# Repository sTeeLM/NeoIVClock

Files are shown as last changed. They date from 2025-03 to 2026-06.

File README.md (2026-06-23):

# NeoIVClock

[简体中文](#简体中文) | [English](#english)

---

## 简体中文

基于 ESP32-S3 主控的环境监测桌面时钟，使用前苏联 IV-18 荧光数码管与 0.96寸 OLED 作为显示输出。

### 功能特性

* **时间管理**：支持 Wi-Fi 连接 NTP 自动对时；支持最多 10 组独立闹钟设置（可配重复周期及声音）；具备秒表与倒计时功能。
* **语音报时**：集成 DFPlayer Mini 模块，支持整点语音报时（可设置免打扰时段）。
* **多维传感器监测**：
  * 温度、湿度 (AHT21)
  * 大气压强 (BMP280)
  * TVOC、eCO2 (ENS160)
  * PM2.5、甲醛等颗粒物及有害气体 (PM5300ST)
* **数据双模上报**：
  * **Wi-Fi**：定时通过自定义 HTTPS 接口发送数据至自建服务器。
  * **蓝牙**：采用 BTHome v2 协议进行 BLE 广播，支持 Home Assistant 免配对直接识别。

### 硬件架构

* **主控**：ESP32-S3 (ESP-IDF 架构)
* **显示**：IV-18 荧光管（主时间） + 0.96寸 OLED（环境数据与配置菜单）
* **供电与驱动**：5V Type-C 输入。通过 XL6007 升压电路产生 30V~50V 高压供给 IV-18，并使用 MAX6921 移位寄存器驱动荧光管。
* **外设连接**：
  * AHT21 / BMP280 / ENS160 / DS3231 挂载于同一路 I2C 总线
  * PM5300ST 与 DFPlayer Mini 分别独占一路 UART 串口

### 关键设计要点

* **温湿度防热干扰布局**：由于板载了 XL6007 高压升压电路，工作时伴随一定的发热量。AHT21 传感器在 PCB 布局时已远离升压区域与 ESP32-S3 主控芯片，并通过 PCB 开槽隔离与外壳独立风道设计，避免了板载热量传导导致的温度偏高、湿度偏低问题。
* **电源去耦与电磁兼容**：PMS5300ST 激光粉尘传感器在风扇启动和采样瞬间存在较大的脉冲电流。供电设计中在 5V 输入端配置了充足的滤波电容，有效解决了因瞬态电压跌落引起的 VFD 屏幕闪烁问题，并做好了走线隔离以避免干扰 DFPlayer 模块的音频输出。
* **VFD 刷新与消隐保护**：使用 MAX6921 驱动 IV-18 荧光管时，在驱动代码中严格控制了刷新占空比并加入动态消隐机制，消除了数码管鬼影。同时引入了软件夜间自动调暗与滚屏保护逻辑，延长荧光管使用寿命并减缓局部老化。
* **双核异步调度与状态机设计**：为了降低多任务并发的复杂度，系统软件引入了状态机设计。同时充分利用了 ESP32-S3 的双核硬件资源：一个核心（Core 0）专门负责系统的 UI 刷新、界面交互与外设控制；另一个核心（Core 1）负责管理传感器数据轮询、UART/I2C 通信以及 Wi-Fi/BLE 物联网协议栈，确保整机在高负载下不卡顿、不丢包。
* **硬件 RTC 时间双重保障**：引入了高精度硬件时钟芯片 DS3231 随 I2C 总线运行。在无网络环境或 Wi-Fi 连接失败时，设备依然能够通过板载电池和高精度温补晶振在断网期间保持高精度的本地走时，与 NTP 网络对时形成双重互补。
* **激光传感器间歇休眠与延寿**：考虑到 PMS5300ST 激光粉尘传感器内的激光二极管与采样风扇存在机械和物理寿命限制，软件设计了间歇采样与低功耗休眠逻辑。传感器无需 24 小时连续运转，而是定时唤醒并预热风扇，完成数据采集后立即将其送入休眠模式，极大延长了传感器的使用寿命并减少了积灰。

### 项目实物

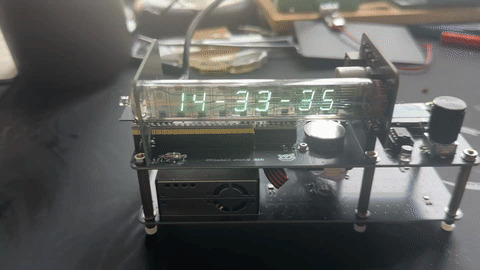
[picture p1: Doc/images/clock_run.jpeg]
图片


视频

### 开源协议

本项目采用 [MIT](LICENSE) 协议开源。

---

## English

An ESP32-S3-based smart desktop clock and environmental monitor, utilizing a USSR IV-18 (ИВ-18) VFD tube and a 0.96" OLED display.

### Features

* **Time Management**: Automatically synchronizes time via Wi-Fi NTP. Supports up to 10 independent alarms with configurable repetition cycles and ringtones. Built-in stopwatch and countdown timer.
* **Voice Chime**: Integrated with a DFPlayer Mini module to support hourly voice announcements with a customizable Do-Not-Disturb period.
* **Multi-Dimensional Environmental Monitoring**:
  * Temperature & Humidity (AHT21)
  * Barometric Pressure (BMP280)
  * TVOC & eCO2 (ENS160)
  * PM2.5, Formaldehyde, and other particulates/hazardous gases (PM5300ST)
* **Dual-Mode Data Reporting**:
  * **Wi-Fi**: Periodically posts environmental data via a custom HTTPS JSON payload to a self-hosted server.
  * **Bluetooth**: Broadcasts via the BTHome v2 protocol, enabling zero-configuration auto-discovery in Home Assistant.

### Hardware Architecture

* **MCU**: ESP32-S3 (Developed natively using ESP-IDF)
* **Display**: IV-18 VFD tube (primary time display) + 0.96" OLED (environmental stats and configuration menu)
* **Power & Drive**: 5V Type-C input. An onboard XL6007 boost converter steps up voltage to 30V~50V for the IV-18 anode/grid, managed via a MAX6921 high-voltage shift register driver.
* **Peripherals Layout**:
  * AHT21 / BMP280 / ENS160 / DS3231 share a single I2C bus.
  * PM5300ST and DFPlayer Mini each utilize a dedicated hardware UART serial interface.

### Key Design Points

* **Thermal Isolation for Environment Sensors**: The onboard XL6007 boost circuit generates noticeable heat during operation. To prevent thermal drift (artificially high temperature and low humidity readings), the AHT21 sensor is positioned far from the boost area and ESP32-S3 MCU, utilizing isolation routing slots on the PCB and dedicated air vents in the enclosure.
* **Power Decoupling & EMC**: The PMS5300ST laser dust sensor draws sharp burst currents when its fan starts and samples. Bulk decoupling capacitors are placed near the 5V rail to prevent transient voltage drops from causing VFD display flicker. Traces are carefully isolated to prevent electromagnetic interference from leaking into the DFPlayer's audio output.
* **VFD Refresh Rate & Blanking Protection**: When driving the IV-18 via the MAX6921, the firmware tightly regulates the duty cycle and implements a dedicated blanking mechanism to eliminate ghosting. Additionally, software-defined night dimming and screen-saver rolling logic are used to mitigate burn-in and prolong the lifespan of the VFD phosphor.
* **Dual-Core Asynchronous Scheduling & State Machine**: To reduce multi-tasking complexity, a robust state machine governs the software architecture. The code harnesses the ESP32-S3's dual-core capability: Core 0 handles UI rendering, user interaction, and peripheral controls, while Core 1 manages sensor polling, UART/I2C buses, and the Wi-Fi/BLE network stacks. This safeguards against UI lag and data packet loss under high system loads.
* **Hardware RTC Time Redundancy**: A high-precision DS3231 RTC chip is integrated into the I2C bus. Backed by a coin cell battery and a temperature-compensated crystal oscillator (TCXO), the clock maintains precise local timekeeping during network outages or Wi-Fi disconnection, forming a robust dual-source time synchronization system with NTP.
* **Intermittent Sampling and Sleep for Laser Sensor**: Given that the laser diode and mechanical fan inside the PMS5300ST have finite operating lifetimes, an intermittent sampling and low-power sleep logic is implemented. Instead of running 24/7, the sensor is woken up periodically to spin up the fan, collect air samples, and immediately enter deep sleep, drastically extending the sensor's service life and preventing dust accumulation.

### Gallery

Video



### License

This project is licensed under the MIT License.

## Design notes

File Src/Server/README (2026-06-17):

使用report_hub机制，将ivclock.py放入report_hub的service.d下，重启服务即可

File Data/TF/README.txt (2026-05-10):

/*
dir 01（misc）:
001: 年
002: 月
003：日
004：时
005：分
006：秒
007: 上午
008: 下午
009：整
010：气温
011：摄氏
012：华氏
013：负
014：点
015：现在时间
016：星期
017: (停顿)
018：度
*/

#define PLAYER_DIR_NUM1 2
/*
dir 02：
001 ~ 003: 十、百、千
*/

#define PLAYER_DIR_NUM2 3
/*
dir 03:
001 ~ 010: 零-九
*/

#define PLAYER_DIR_ALARM 4
/*
dir 04（闹钟）：
001 ~ 010：闹钟声音
*/

#define PLAYER_DIR_EFECTS 5
/*
dir 05（音效）：
001 ~ 010：音效声音
*/

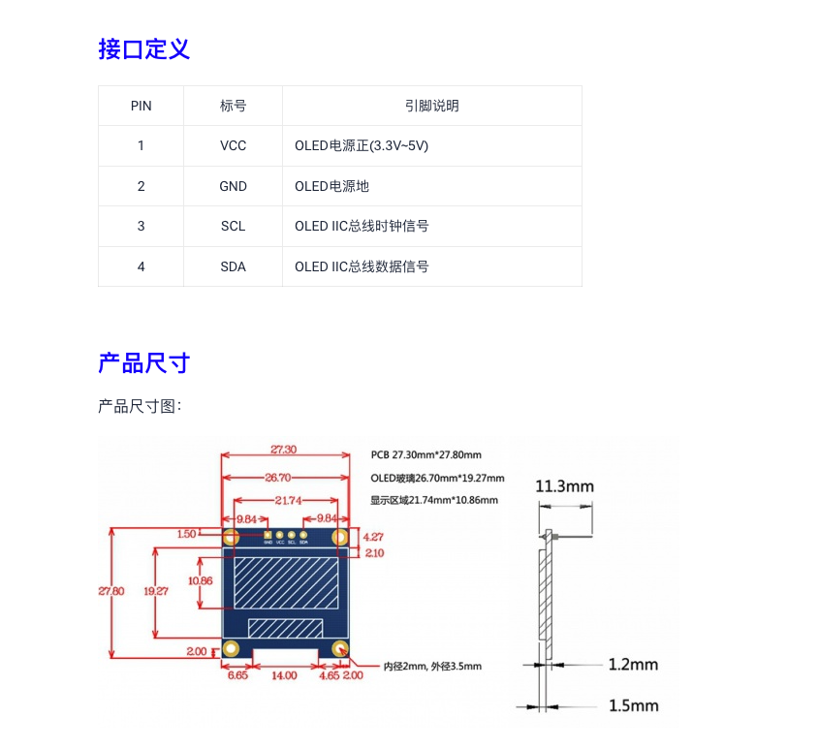
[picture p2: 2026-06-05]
Doc/datasheets/0.96inch-OLED-MC096VX-schematic-diagram.png

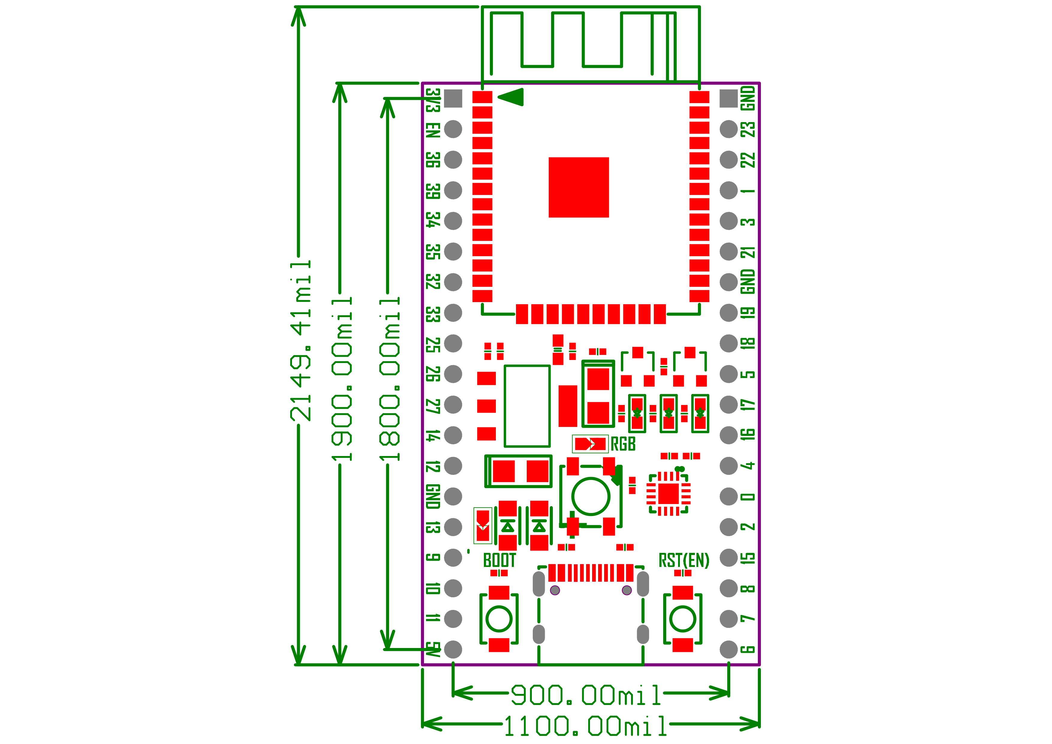
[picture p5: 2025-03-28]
Doc/YD-ESP32/ESP32-SIZE.png

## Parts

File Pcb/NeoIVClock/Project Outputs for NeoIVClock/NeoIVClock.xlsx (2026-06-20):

Line # | Designator | Value | Name | Description | Quantity
 | B1 |  | AMS1117 | 1117 | 1
 | B2 |  | RT9193-18 |  | 1
 | BT1 |  | ML2032 | Multicell Battery | 1
 | C1 | 22uF | 16V | Polarized Capacitor (Radial) | 1
 | C2 | 470uF | 25V | Polarized Capacitor (Radial) | 1
 | C3, C4, C5, C6, C7, C8, C9, C10, C11, C12, C20, C21, C22 | 104 | 50V | Capacitor | 13
 | C13 | 220uF | 100V | Polarized Capacitor (Radial) | 1
 | C14, C17, C18 | 105 | 100V | Capacitor | 3
 | C15 | 47uF | 50V | Polarized Capacitor (Radial) | 1
 | C16 | 105 | 50V | Capacitor | 1
 | C19 | 223 | 50V | Capacitor | 1
 | C23, C24 | 106 | 10V | Capacitor | 2
 | CON1 |  | USB-TYPEE_C | USB-TYPEE_C | 1
 | D1, D2 |  | S4 | Schottky Diode | 2
 | D3 |  | 5800B | Default Diode | 1
 | D4 |  | SS310 | Schottky Diode | 1
 | HG1 |  | HG Switch |  | 1
 | K1 |  | EC11 |  | 1
 | L1, L2 | 600R | 400mA | Inductor | 2
 | L3 | 33uH | 4A | Inductor | 1
 | OLED1 |  | OLED_96 |  | 1
 | P1, P7 |  | Header 15X2 | Header, 15-Pin, Dual row | 2
 | P2, P4, P5, P6 |  | Header 2X2 | Header, 2-Pin, Dual row | 4
 | P3, P8 |  | Header 10 | Header, 10-Pin | 2
 | Q1 |  | S8050 (J3Y) | NPN Bipolar Transistor | 1
 | Q2 |  | AO3400 | N-Channel MOSFET | 1
 | Q3, Q4 |  | SI2302 | N-Channel MOSFET | 2
 | R1 | 10R | Res1 | Resistor | 1
 | R2, R5, R6, R7, R8, R9, R12, R14, R15, R18, R19 | 10K | Res1 | Resistor | 11
 | R3, R17 | 1K | Res1 | Resistor | 2
 | R4 | 100K | Res1 | Resistor | 1
 | R10, R11, R20 |  | 8P4R-10K |  | 3
 | R13 | 4K7 | Res1 | Resistor | 1
 | R16 | 39K | Res1 | Resistor | 1
 | R21, R22 | 5K1 | Res1 | Resistor | 2
 | SPEAKER1 |  | SPEAKER |  | 1
 | T1 |  | IV18 |  | 1
 | U1 |  | BEEPER |  | 1
 | U2 |  | ESP32-S3-N16R8-BOARD |  | 1
 | U3 |  | DS3231SN# | Real Time Clock Serial Maxim DS3231SN# Real Time Clock, Battery Backup, Calendar, Clock, I2C, 5.5 V, 16-Pin SOIC | 1
 | U4 |  | DPF_PLAYER |  | 1
 | U5 |  | LM358P |  | 1
 | U6 |  | CD4040BE |  | 1
 | U7 |  | AT24C32 |  | 1
 | U8 |  | MAX6921AWI |  | 1
 | U9 |  | XL6007 |  | 1
 | U10 |  | PMS5003ST |  | 1
 | U11 |  | ENS160 | ENS160 | 1
 | U12 |  | BMP280 |  | 1
 | U13 |  | AHT20 |  | 1

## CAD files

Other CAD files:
Shell/OLED面板.dwg

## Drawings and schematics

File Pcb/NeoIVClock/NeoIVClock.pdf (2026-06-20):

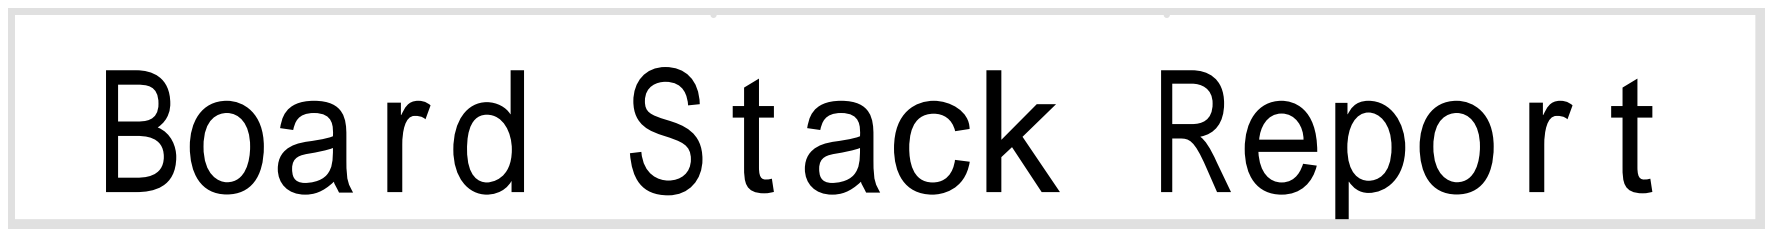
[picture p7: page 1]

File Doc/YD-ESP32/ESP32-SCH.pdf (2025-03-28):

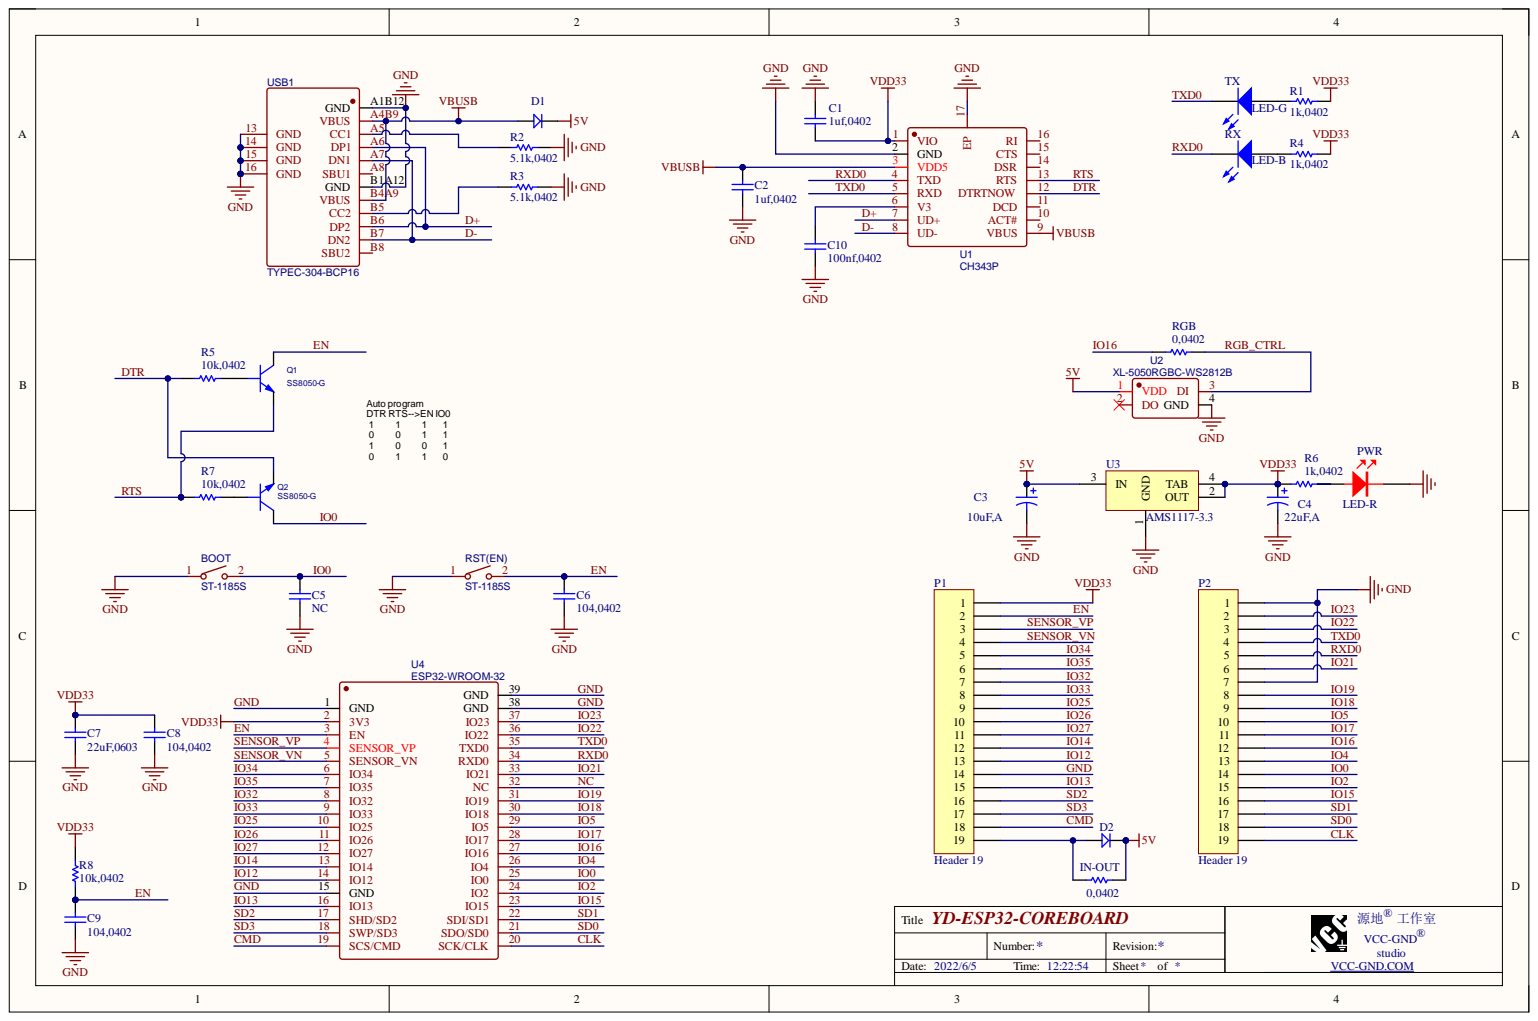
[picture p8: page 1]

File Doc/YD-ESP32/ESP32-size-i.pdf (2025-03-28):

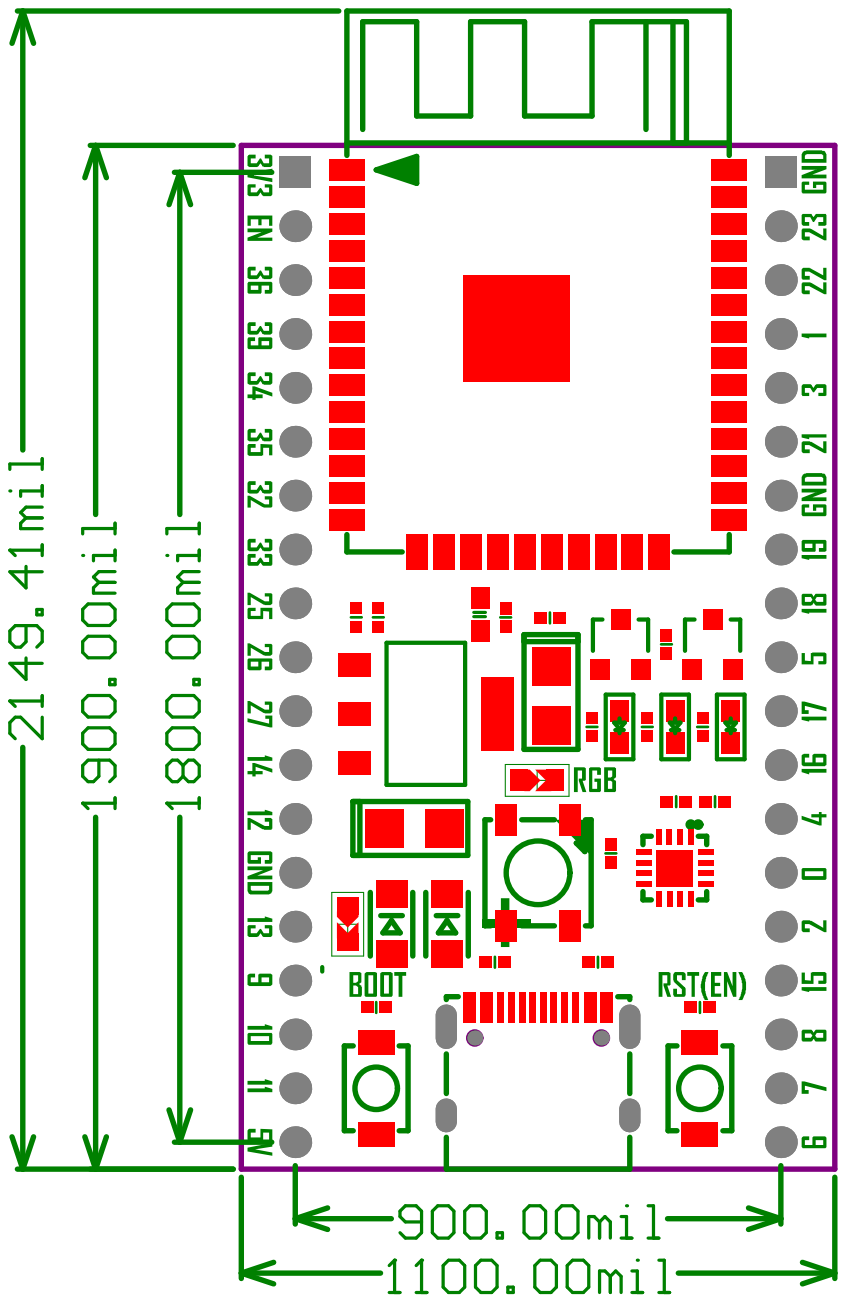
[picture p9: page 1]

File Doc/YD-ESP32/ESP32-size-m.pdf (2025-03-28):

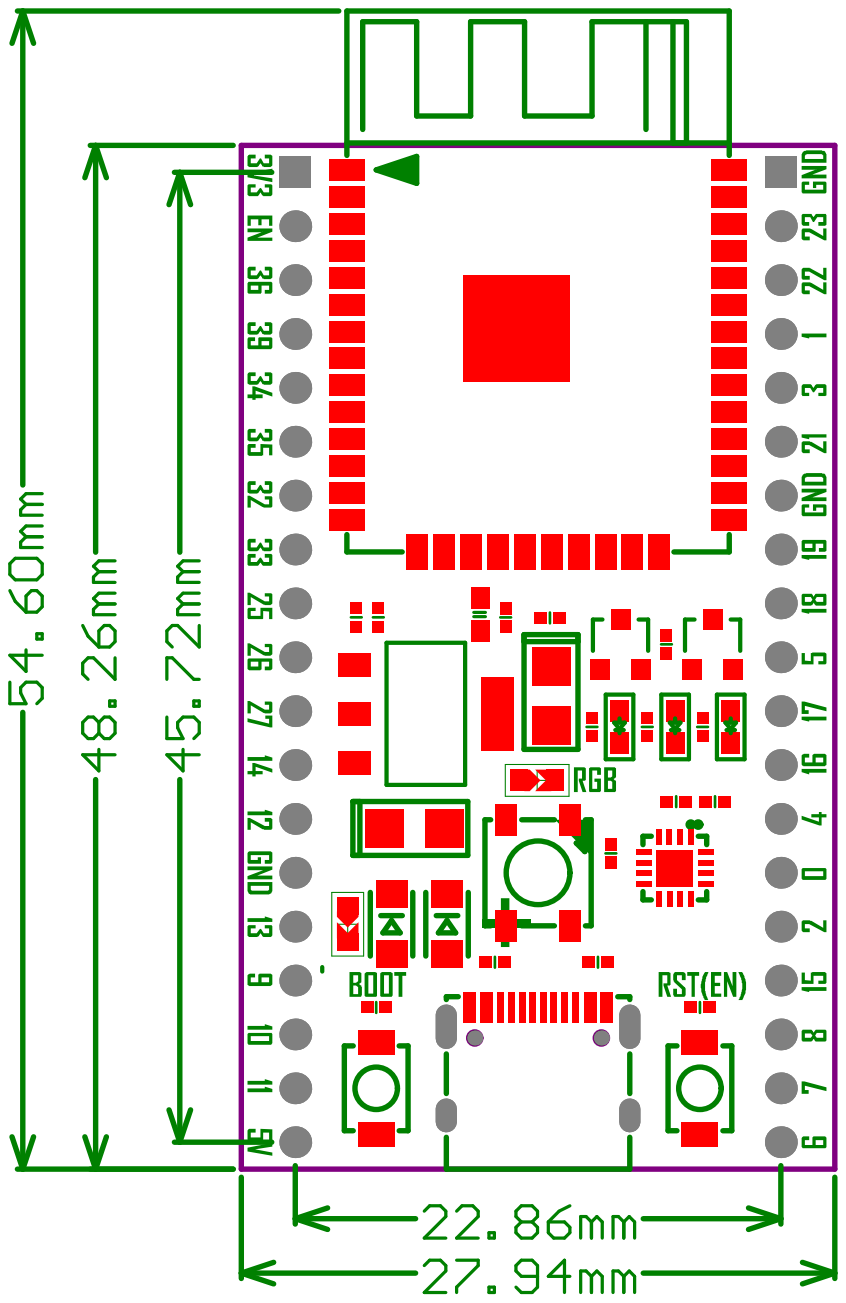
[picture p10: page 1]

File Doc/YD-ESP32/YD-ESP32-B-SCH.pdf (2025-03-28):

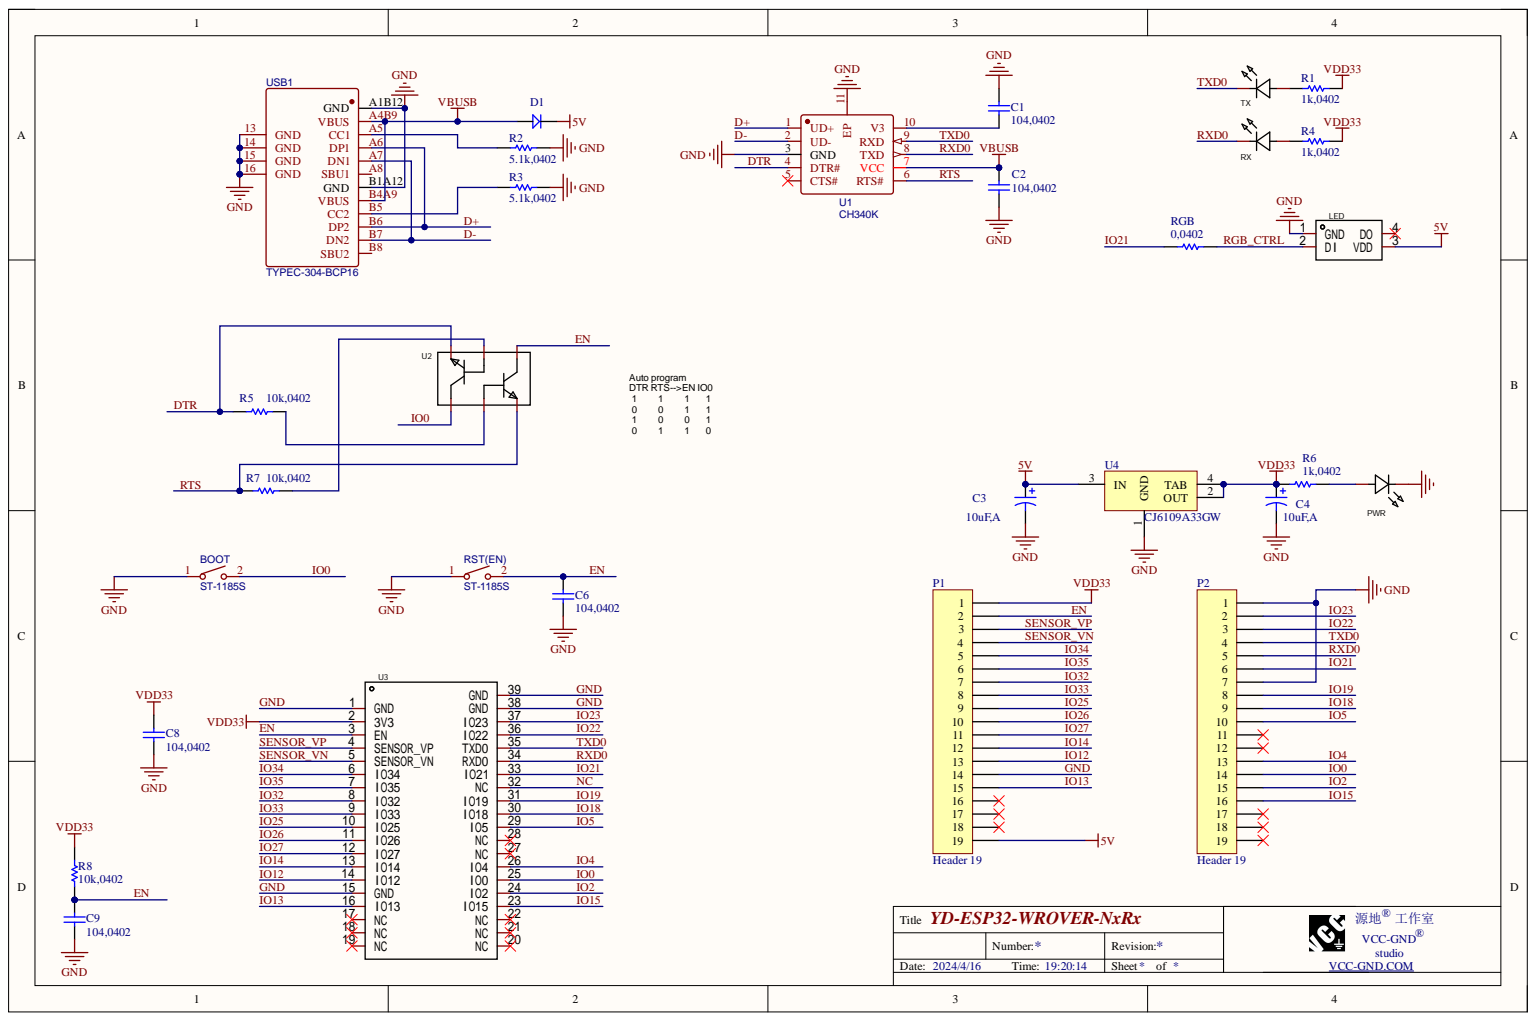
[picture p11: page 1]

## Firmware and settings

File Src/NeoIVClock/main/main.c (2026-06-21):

#include "alarm.h"
#include "beeper.h"
#include "ec11.h"
#include "clock.h"
#include "config.h"
#include "delay.h"
#include "iv18.h"
#include "bmp280.h"
#include "dpf_player.h"
#include "ds3231_rtc.h"
#include "gpio_wrapper.h"
#include "i2c_wrapper.h"
#include "logger.h"
#include "motion_sensor.h"
#include "player.h"
#include "rom.h"
#include "sm.h"
#include "task.h"
#include "terminal.h"
#include "timer.h"
#include "oled.h"
#include "oled_ext.h"
#include "pms5003st.h"
#include "light_sensor.h"
#include "usart_wrapper.h"
#include "aux_main.h"
#include "sensor_data.h"
#include "reporter.h"
#include "oled_ext.h"
#include "mini_font.h"
#include "nm.h"
#include "aht20.h"
#include "ws2812b.h"
#include "ens160.h"
#include "esp32_temp.h"
#include "cjson_wrapper.h"
#include "nvs_wrapper.h"
#include "blem.h"

#include "freertos/FreeRTOS.h"
#include "freertos/task.h"
#include "esp_cpu.h" 

#include <time.h>

static const char * TAG = "APP_MAIN";

void app_main(void)
{
  // 时区配置
  setenv("TZ", "CST-8", 1);
  tzset(); 

  // 核心组件的初始化
  logger_init();
  delay_init();

  NEO_LOGI(TAG, "Starting up...on CPU%u", esp_cpu_get_core_id());
  
  // 初始化硬件接口
  gpio_wrapper_init();
  usart_wrapper_init();
  i2c_wrapper_init();

  // 初始化底层硬件，注意顺序，ec11_init要在最前面
  ec11_init();
  rom_init();
  config_init(); // 这个是软件，由于后面的初始化可能会读配置，所以放在底层硬件初始化之后 
  mini_font_init(); // 字库可能被 OLED使用，所以放在这里初始化
  oled_init();  
  oled_ext_print_progress(0, L"启动..系统");
  ws2812b_init();
  esp32_temp_init();
  light_sensor_init();
  iv18_init();
  oled_ext_print_progress(10, L"启动..iv18");
  oled_ext_init();
  beeper_init();
  oled_ext_print_progress(15, L"启动..BEEPER");
  ds3231_rtc_init();
  oled_ext_print_progress(20, L"启动..DS3131");
  motion_sensor_init();
  oled_ext_print_progress(25, L"启动..震动传感器");
  bmp280_init();
  oled_ext_print_progress(30, L"启动..BM280");
  aht20_init();
  oled_ext_print_progress(35, L"启动..AHT20");
  dpf_player_init();
  oled_ext_print_progress(40, L"启动..DPF");
  pms5003st_init();
  oled_ext_print_progress(45, L"启动..PMS5003");
  ens160_init();
  oled_ext_print_progress(50, L"启动..ENS160");
  
  // 初始化其他软件设备
  cjson_wrapper_init(); 
  clock_init();
  oled_ext_print_progress(55, L"启动..时钟");
  alarm_init();
  timer_init();
  terminal_init();
  player_init();
  reporter_init();
  sensor_data_init();
  oled_ext_print_progress(60, L"启动..任务"); 
  nvs_wrapper_init();
  blem_init();
  nm_init();
  task_init();
  sm_init();
 
  beeper_beep();
  delay_ms(1000);
  beeper_beep_beep();

  // 在另一个core上启动事件循环
  aux_main_start();

  oled_ext_print_progress(80, L"启动..网络"); 
  nm_start_sta_daemon();

  oled_ext_print_progress(100, L"完成!"); 

  NEO_LOGI(TAG, "will enter event loop on CPU%d", esp_cpu_get_core_id());
  // 跑事件循环
  while(1) {
    task_run();
    task_rcv_ipc();
  }
}

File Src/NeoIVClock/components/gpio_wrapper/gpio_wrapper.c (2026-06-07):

#include "gpio_wrapper.h"
#include "hal/gpio_types.h"
#include "logger.h"
#include "driver/gpio.h"

static const char * TAG = "GPIO";

void gpio_wrapper_init(void)
{
  gpio_config_t io_iv18_conf = {};
  gpio_config_t io_i2c_conf = {};
  gpio_config_t io_ds3231_conf = {};
  gpio_config_t io_ec11_conf = {};
  gpio_config_t io_beeper_conf = {};
  gpio_config_t io_motion_conf = {};
  gpio_config_t io_dpf_player_conf = {};
  gpio_config_t io_pm5003st_conf = {};

  NEO_LOGI(TAG, "init");
  //NEO_LOGI(TAG, "before gpio_dump_io_configuration:\n");
  //gpio_dump_io_configuration(stdout, SOC_GPIO_VALID_GPIO_MASK);
  esp_intr_dump(NULL);

  // 设置iv18相关GPIO
  //disable interrupt
  io_iv18_conf.intr_type = GPIO_INTR_DISABLE;
  //set as output mode
  io_iv18_conf.mode = GPIO_MODE_OUTPUT;
  //bit mask of the pins that you want to set,e.g.GPIO18/19
  io_iv18_conf.pin_bit_mask = 
    (1ULL << IV18_EN_GPIO_PIN)  | 
    (1ULL << IV18_CLK_GPIO_PIN) |
    (1ULL << IV18_DIN_GPIO_PIN) |
    (1ULL << IV18_LOAD_GPIO_PIN) |
    (1ULL << IV18_BLANK_GPIO_PIN);
  //disable pull-down mode
  io_iv18_conf.pull_down_en = GPIO_PULLDOWN_DISABLE;
  //disable pull-up mode
  io_iv18_conf.pull_up_en = GPIO_PULLUP_DISABLE;
  //configure GPIO with the given settings
  ESP_ERROR_CHECK(gpio_config(&io_iv18_conf));

 
  // 设置i2c相关GPIO
  io_i2c_conf.intr_type = GPIO_INTR_DISABLE;
  io_i2c_conf.mode = GPIO_MODE_INPUT_OUTPUT_OD;
  io_i2c_conf.pin_bit_mask = 
    (1ULL << I2C_SCL_GPIO_PIN) |
    (1ULL << I2C_SDA_GPIO_PIN);
  io_i2c_conf.pull_down_en = GPIO_PULLDOWN_DISABLE;
  io_i2c_conf.pull_up_en = GPIO_PULLDOWN_DISABLE;
  ESP_ERROR_CHECK(gpio_config(&io_i2c_conf));
 
  
  // 设置ds3231相关GPIO
  io_ds3231_conf.intr_type = GPIO_INTR_DISABLE;
  io_ds3231_conf.mode = GPIO_MODE_INPUT;
  io_ds3231_conf.pin_bit_mask = 
    (1ULL << DS3231_CLK_GPIO_PIN|DS3231_INT_GPIO_PIN);
  io_ds3231_conf.pull_down_en = GPIO_PULLDOWN_DISABLE;
  io_ds3231_conf.pull_up_en = GPIO_PULLDOWN_DISABLE;
  ESP_ERROR_CHECK(gpio_config(&io_ds3231_conf));
  
  // 设置EC11相关GPIO
  io_ec11_conf.intr_type = GPIO_INTR_DISABLE;
  io_ec11_conf.mode = GPIO_MODE_INPUT;
  io_ec11_conf.pin_bit_mask = 
    (1ULL << EC11_B_GPIO_PIN) |
    (1ULL << EC11_C_GPIO_PIN) |
    (1ULL << EC11_A_GPIO_PIN);
  io_ec11_conf.pull_down_en = GPIO_PULLDOWN_DISABLE;
  io_ec11_conf.pull_up_en = GPIO_PULLUP_ENABLE;
  ESP_ERROR_CHECK(gpio_config(&io_ec11_conf));

  // 设置Beeper相关GPIO
  io_beeper_conf.mode = GPIO_MODE_OUTPUT;
  io_beeper_conf.intr_type = GPIO_INTR_DISABLE; 
  io_beeper_conf.pin_bit_mask = (1ULL << BEEPER_GPIO_PIN);
  io_beeper_conf.pull_down_en = GPIO_PULLDOWN_DISABLE;
  io_beeper_conf.pull_up_en = GPIO_PULLUP_DISABLE;
  ESP_ERROR_CHECK(gpio_config(&io_beeper_conf));

  // 设置运动传感器开关相关GPIO
  io_motion_conf.mode = GPIO_MODE_INPUT;
  io_motion_conf.intr_type = GPIO_INTR_DISABLE;
  io_motion_conf.pin_bit_mask = (1ULL << MOTION_SW_GPIO_PIN);
  io_motion_conf.pull_down_en = GPIO_PULLDOWN_DISABLE;
  io_motion_conf.pull_up_en = GPIO_PULLUP_ENABLE;
  ESP_ERROR_CHECK(gpio_config(&io_motion_conf));

  // 设置DPF Player相关GPIO
  io_dpf_player_conf.mode = GPIO_MODE_INPUT;
  io_dpf_player_conf.intr_type = GPIO_INTR_DISABLE;
  io_dpf_player_conf.pin_bit_mask = (1ULL << DPF_PLAYER_BSY_GPIO_PIN);
  io_dpf_player_conf.pull_down_en = GPIO_PULLDOWN_DISABLE;
  io_dpf_player_conf.pull_up_en = GPIO_PULLUP_ENABLE;
  ESP_ERROR_CHECK(gpio_config(&io_dpf_player_conf));

  // 设置DPM5003ST相关GPIO定义
  io_pm5003st_conf.mode = GPIO_MODE_OUTPUT;
  io_pm5003st_conf.intr_type = GPIO_INTR_DISABLE;
  io_pm5003st_conf.pin_bit_mask = (1ULL << PMS5003ST_SET_GPIO_PIN) | (1ULL << PMS5003ST_RESET_GPIO_PIN);
  io_pm5003st_conf.pull_down_en = GPIO_PULLDOWN_DISABLE;
  io_pm5003st_conf.pull_up_en = GPIO_PULLUP_DISABLE;
  ESP_ERROR_CHECK(gpio_config(&io_pm5003st_conf));

  gpio_install_isr_service(ESP_INTR_FLAG_LEVEL1);

  //NEO_LOGI(TAG, "after gpio_dump_io_configuration:\n");
  gpio_dump_io_configuration(stdout, SOC_GPIO_VALID_GPIO_MASK);

}


void gpio_wrapper_set_level(uint32_t gpio_num, uint8_t level)
{
  ESP_ERROR_CHECK(gpio_set_level((gpio_num_t)gpio_num, level));
}

uint8_t gpio_wrapper_get_level(uint32_t gpio_num)
{
  uint8_t ret = 0;
  int val = gpio_get_level((gpio_num_t)gpio_num);
  if(val < 0) {
    NEO_EARLY_LOGE(TAG, "gpio_get_level failed for gpio %u", gpio_num);
  } else {
    ret = (uint8_t)val;
  }
  return ret;
}

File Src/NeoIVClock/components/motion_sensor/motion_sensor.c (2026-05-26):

#include "motion_sensor.h"
#include "clock.h"
#include "logger.h"
#include "config.h"
#include "gpio_wrapper.h"
#include "esp_err.h"
#include "driver/gpio.h"
#include "driver/gpio_filter.h"
#include "task.h"

static const char * TAG = "MOTION";
static bool motion_en = false;

#define MOTION_SENSOR_DELAY_SEC 3
static uint32_t motion_last_trigger_sec;

static void IRAM_ATTR motion_sensor_isr_handler (void* param)
{
  if(!motion_en) {
    return;
  }
  if(clock_diff_now_sec(motion_last_trigger_sec) > MOTION_SENSOR_DELAY_SEC) {
    NEO_EARLY_LOGD(TAG, "Motion sensor triggered!");
    task_set(EV_ACC);
    motion_last_trigger_sec = clock_get_now_sec();
  }
}

void motion_sensor_init(void)
{
  gpio_pin_glitch_filter_config_t glitch_cfg_motion = {
    .gpio_num = MOTION_SW_GPIO_PIN, 
    .clk_src = GLITCH_FILTER_CLK_SRC_DEFAULT,
  };
  gpio_glitch_filter_handle_t glitch_handle_motion;

  NEO_LOGI(TAG, "init");
  ESP_ERROR_CHECK(gpio_intr_enable(MOTION_SW_GPIO_PIN));
  ESP_ERROR_CHECK(gpio_set_intr_type(MOTION_SW_GPIO_PIN, GPIO_INTR_NEGEDGE));
  ESP_ERROR_CHECK(gpio_isr_handler_add(MOTION_SW_GPIO_PIN, motion_sensor_isr_handler, NULL));
  ESP_ERROR_CHECK(gpio_new_pin_glitch_filter(&glitch_cfg_motion, &glitch_handle_motion));
  ESP_ERROR_CHECK(gpio_glitch_filter_enable(glitch_handle_motion));
  motion_en = config_read_int("motion_en") != 0;
  NEO_LOGD(TAG, "motion_en = %d", motion_en);
  motion_last_trigger_sec = clock_get_now_sec();
}

bool motion_sensor_test_enable(void)
{
  return motion_en;
}

bool motion_sensor_enable(bool enable)
{
  motion_en = enable;
  return enable;
}

void motion_sensor_save_config(void)
{
  config_write_int("motion_en", motion_en != 0);
}

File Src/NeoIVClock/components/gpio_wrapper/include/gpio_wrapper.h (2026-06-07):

#ifndef NEO_IV_CLOCK_GPIO_WRAPPER_H
#define NEO_IV_CLOCK_GPIO_WRAPPER_H

#include <stdint.h>

void gpio_wrapper_init(void);

// IV18相关GPIO定义
#define IV18_DIN_GPIO_PIN    38
#define IV18_LOAD_GPIO_PIN   39
#define IV18_CLK_GPIO_PIN    40
#define IV18_BLANK_GPIO_PIN  41
#define IV18_EN_GPIO_PIN     42


// I2C相关GPIO定义
#define I2C_SCL_GPIO_PIN     6
#define I2C_SDA_GPIO_PIN     7

// DS3231的时钟信号GPIO定义
#define DS3231_CLK_GPIO_PIN    15
#define DS3231_INT_GPIO_PIN    5

// EC11相关GPIO定义
#define EC11_A_GPIO_PIN       13
#define EC11_B_GPIO_PIN       12
#define EC11_C_GPIO_PIN       14

// Beeper 相关GPIO定义
#define BEEPER_GPIO_PIN       16

// 运动传感器开关相关GPIO定义
#define MOTION_SW_GPIO_PIN    17

// DPF Player相关GPIO定义
#define DPF_PLAYER_BSY_GPIO_PIN 18
#define DPF_PLAYER_RX_GPIO_PIN  19
#define DPF_PLAYER_TX_GPIO_PIN  20

// PM5003ST相关GPIO定义
#define PMS5003ST_SET_GPIO_PIN    10
#define PMS5003ST_RESET_GPIO_PIN  11
#define PMS5003ST_TX_GPIO_PIN    8 
#define PMS5003ST_RX_GPIO_PIN    9

// LED灯相关GPIO定义
#define LED_STRIP_GPIO_PIN      48

// GPIO操作接口 
void gpio_wrapper_set_level(uint32_t gpio_num, uint8_t level);
uint8_t gpio_wrapper_get_level(uint32_t gpio_num);
#endif //NEO_IV_CLOCK_GPIO_WRAPPER_H

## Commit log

2025-03-28 build system work！
2025-03-31 finish framework
    框架已经完成了
2026-04-25 Temp Save：完成了框架，开始搭建面包板Demo
    [NeoIVClock.PrjPcb, NeoIVClock.SchDoc]
2026-04-26 添加了一些datasheet
2026-05-01 ESP32 board is burned， so we switch to ESP32-S2 board
    [gpio_wrapper.c, gpio_wrapper.h, iv18.c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]
2026-05-02 移植ds3231中，临时保存
2026-05-03 ds3231移植完毕了
2026-05-07 完成了许多外设，整理了一部分datasheet
    外设：
    1. alarm
    2. beeper
    3. ec11
2026-05-08 移植完了rom，config，修改了clock，clock现在不依赖RTC处理闰年了！
2026-05-09 移植完毕了气压计，dpf_player搞了一半，不能编译！！！！
2026-05-10 完成了dpf_player的移植
2026-05-10 player移植完成
2026-05-11 oled点亮，几个高级函数还没有写
2026-05-13 finish oled_draw_rect, fix bug in rom_write
    [main.c, oled.c, rom.c]
2026-05-14 finish oled driver
2026-05-15 1. oled:将代码中若干屏幕尺寸相关常数换成宏定义。 2, light_sensor: 读数错误返回-1。
2026-05-15 1. 完成了最麻烦的task和sm的框架移植
2026-05-15 遗漏了SM_NULL的对应字符串名
2026-05-15 很羞耻地被AI查出了bug，修改一下免得忘掉了
2026-05-16 完成了双核状态机的框架
2026-05-16 自动识别，将main和aux_main运行在不同核心
2026-05-17 1. 完成了双核工作框架 2. 完成了sensor_data模块
2026-05-19 add reporter
    [partitionTable.csv]
2026-05-20 可以显示跳动的时间和滚动的日期了
2026-05-20 IV18自动亮度控制
2026-05-20 启用了PSRAM
2026-05-21 添加了IV18在sm_clock下PS（Power Save）关闭的功能
2026-05-21 添加了震动传感器的延时逻辑
2026-05-21 OLED屏幕可以显示大气数据了
2026-05-22 1. 修正了开机之后，所有大气数据读数为0的问题 2. 添加了一下图标
    [main.c, pms5003st.c]
2026-05-22 1. 完成了SM_FUNC_SELECT
2026-05-22 刷新oled时先息屏
2026-05-23 sm_set_alarm的主体逻辑已经写完了，决定先实现字库
2026-05-23 实现了mini_font，这下OLED上打印字符串再也不愁了
2026-05-24 完成了SM_ALARM状态机
2026-05-24 完全解决了OLED屏幕闪烁的问题，要点是维持缓冲区，然后一次性绘制完毕，少清除屏幕
2026-05-25 1. 完成了SM_SET_TIME 2. 修正了Alarm小时模60的可笑bug 3. 调整时间时，会暂停IV字段的闪烁，看得更清楚一些
    [clock.c, oled.c]
2026-05-25 完成了SM_SET_DATE: 大量copy代码，不要脸了
2026-05-26 用AI写了生成字体的程序，字体自由了
2026-05-26 1. 完成了SM_SET_PARAM 2. 实现了中文字体自由，在AI的帮助下
2026-05-26 删除了一些垃圾代码，由于实现了汉字自由，不用画ICON了
2026-05-26 alarm 添加了一次性闹钟的逻辑
2026-05-26 给OLED添加了对比度调整和黑底白字/白底黑字的选项
2026-05-27 1. 完成了SM_TIMER
2026-05-27 1. 完成了SM_STOP_WATCH
2026-05-28 优化了一些状态机的交互
2026-05-28 1. 修改了数据上报机制，在整点固定上报，同时兼顾PSM5003ST的休眠 2. 搞定了PMS5003ST不能休眠的问题，除了线接错，checksum也算错，PMS5003的文档和屎一样 3. 优化了DPF的初始化代码 4. TODO：串口接收代码需要重写
    [clock.c, dpf_player.c, gpio_wrapper.c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]
2026-05-29 1. 重新写了读取串口帧的函数（AI） 2. 修正了clock中一个整数溢出的bug
    [clock.c, dpf_player.c, pms5003st.c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]
2026-05-30 添加了network_manager
2026-05-30 WIFI联网代码也写完了
2026-05-31 完成了配网服务
2026-05-31 添加了“网络对时”的选项
2026-05-31 添加了about
2026-06-01 1. 启用了AHT20温度湿度计 2. 完成了上报、接收代码，未有测试 3. 修改了上报定时逻辑，最短1分钟
    [partitions_16mb.csv]
2026-06-02 服务程序也全部写完了
2026-06-02 第一版本的代码貌似写完了！
2026-06-02 优化了sm_sensor的逻辑。不过貌似这样改不用状态机了。。。
2026-06-03 音效、闹钟完全调通
2026-06-04 1. ntp时间同步在质数间隔3593秒而不是3600秒 2. clock初始化后通过settimeofday设置系统时间
2026-06-04 1. SM_FUNC_SELECT长时间不操作，会自动返回到SM_CLOCK
2026-06-04 Fix: prevent nm dynamic HTML buffer overflow; add QR data size check
    - Replace unsafe strcpy/strcat in nm_index_get_handler with snprintf-based appends
    - Return error when input data exceeds QR code capacity in qrcode_initBytes
2026-06-04 Fix: return error for invalid led model instead of assert\n\nReplace assert(false) with error return in rmt_new_led_strip_encoder to avoid hard abort in production.\n\nCo-authored-by: Copilot <223556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
2026-06-04 1. bugfix: SM_FUNC_SELECT不能超时跳回SM_CLOCK
2026-06-04 add some foot print to pcb lib
2026-06-05 1. bugfix: AHT20读数不对
2026-06-05 finish scheme
    [BottomPanel.SchDoc, LeftPannel.SchDoc, NEOIVClock.PcbDoc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]
2026-06-05 温度使用aht20
2026-06-06 1. ROM代码完整支持了AT的全系列ROM芯片
2026-06-06 checking sch
    [BottomPanel.SchDoc, LeftPannel.SchDoc, NeoIVClock.PrjPcb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]
2026-06-07 1. 选择音效的时候能实时听到效果
2026-06-07 1. PCBÍê³ÉÁËÍâÐÎÉè¼ƺÍÅŲ¼
    [BottomPanel.SchDoc, LeftPannel.SchDoc, NEOIVClock.PcbDoc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]
2026-06-07 1. 给整点报时添加了指定时间段的能力 2. 将clock的数据结构内部day字段修改为0代表周日，简化逻辑避免bug 3. 修正了网络对时关闭不掉的bug 4. 修正了player在周日报告星期几不正确的bug
    [clock.c]
2026-06-08 1. CLOCK：ishour12现在通过函数读取，而不是直接读取clk结构的字段 2. CLOCK：添加了避免由于时钟同步，频繁写入ROM的问题，尽量减少ROM的磨损
    [clock.c]
2026-06-08 1. PCB画完了，等待检查
    [BottomPanel.SchDoc, LeftPannel.SchDoc, NEOIVClock.PcbDoc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]
2026-06-09 完成PCB
    [BottomPanel.SchDoc, NEOIVClock.PcbDoc, RightPannel.SchDoc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]
2026-06-10 1. 添加了ENS160，准备换传感器了
2026-06-10 1. 更换了TVOC传感器
    [BottomPanel.SchDoc, LeftPannel.SchDoc, NEOIVClock.PcbDoc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]
2026-06-12 1.添加了主控芯片和时钟芯片的温度读数
2026-06-12 不小心更新错了ivclock_server.py
2026-06-13 1. 调整了传感器芯片的位置，优化热耦合 2. 优化了温度计周围的CNC挖槽
    [NEOIVClock.PcbDoc]
2026-06-13 1. 修正了WIFI天线位置开窗的bug
    [NEOIVClock.PcbDoc]
2026-06-14 1. 大改了一版本PCB，变成细长条的了，EC11旋钮、OLED位置更合理
    [BottomPanel.SchDoc, LeftPannel.SchDoc, NEOIVClock.PcbDoc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]
2026-06-15 1. 改了一点bug，加宽了PCB4MM
    [NEOIVClock.PcbDoc]
2026-06-17 使用report_hub
2026-06-18 1. 将上报和NTP服务的默认地址修改为：data.madcat.cc
2026-06-18 1. 修正了http客户端上报代码，可以正确处理返回值
2026-06-20 1. 焊接电路板的时候做了一点修正（电阻值标错），OLED外框画错
    [BottomPanel.SchDoc, NEOIVClock.PcbDoc, NeoIVClock.PrjPcb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]
2026-06-20 1.组装完毕后，发现EC11旋转方向反了，而且需要加50us的延时，看起来电路板和模块似乎不一致
2026-06-21 1. 添加了蓝牙通过BTHome上报数据的功能
2026-06-21 1. 添加了ug/m3的图标
2026-06-21 1. 修正了PM2.5显示缺乏单位的bug
2026-06-22 1. 添加了OLED的亚克力外壳CAD文件
    [OLED面板.dwg]
2026-06-22 1. 添加了遗漏的蓝牙代码 2. 修正了IV18自动光照的bug：在全黑环境下计算错误导致亮度100%
    [iv18.c]
